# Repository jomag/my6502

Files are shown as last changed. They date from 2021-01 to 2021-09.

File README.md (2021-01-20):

# My 6502

I started watching [Ben Eaters](https://eater.net) [video series](https://eater.net/8bit)
where he builds a 6502 (actually, 65C02) based 8-bit computer from scratch
on breadboards. I thought it could be fun to follow along and build something similar,
but using real PCB's cause breadboards drive me crazy.

It might end up being something pretty to hang on the wall...

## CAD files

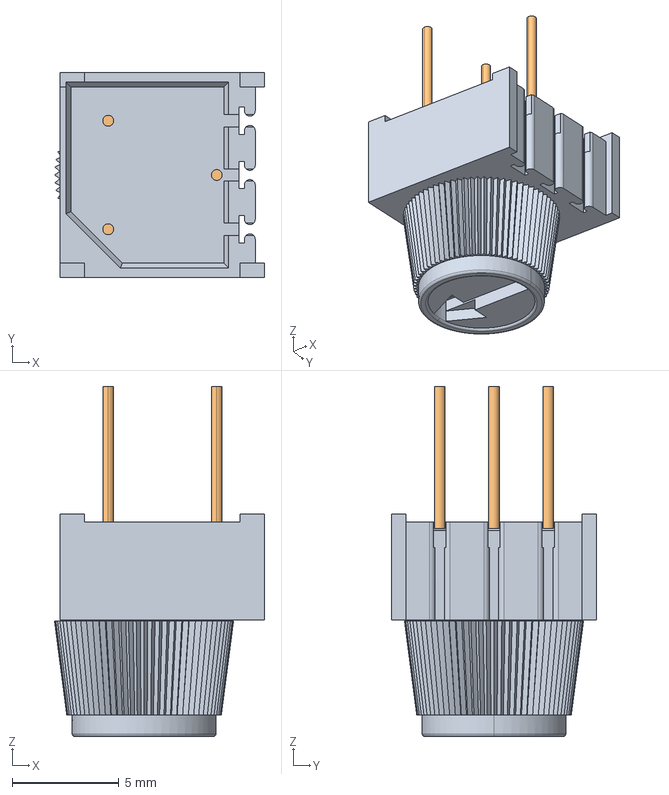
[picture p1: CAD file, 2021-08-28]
3d/3386F(T).stp
9.83 x 9.58 x 16.4 mm
MANIFOLD_SOLID_BREP_18751
MANIFOLD_SOLID_BREP_18840
MANIFOLD_SOLID_BREP_18929
MANIFOLD_SOLID_BREP_19018

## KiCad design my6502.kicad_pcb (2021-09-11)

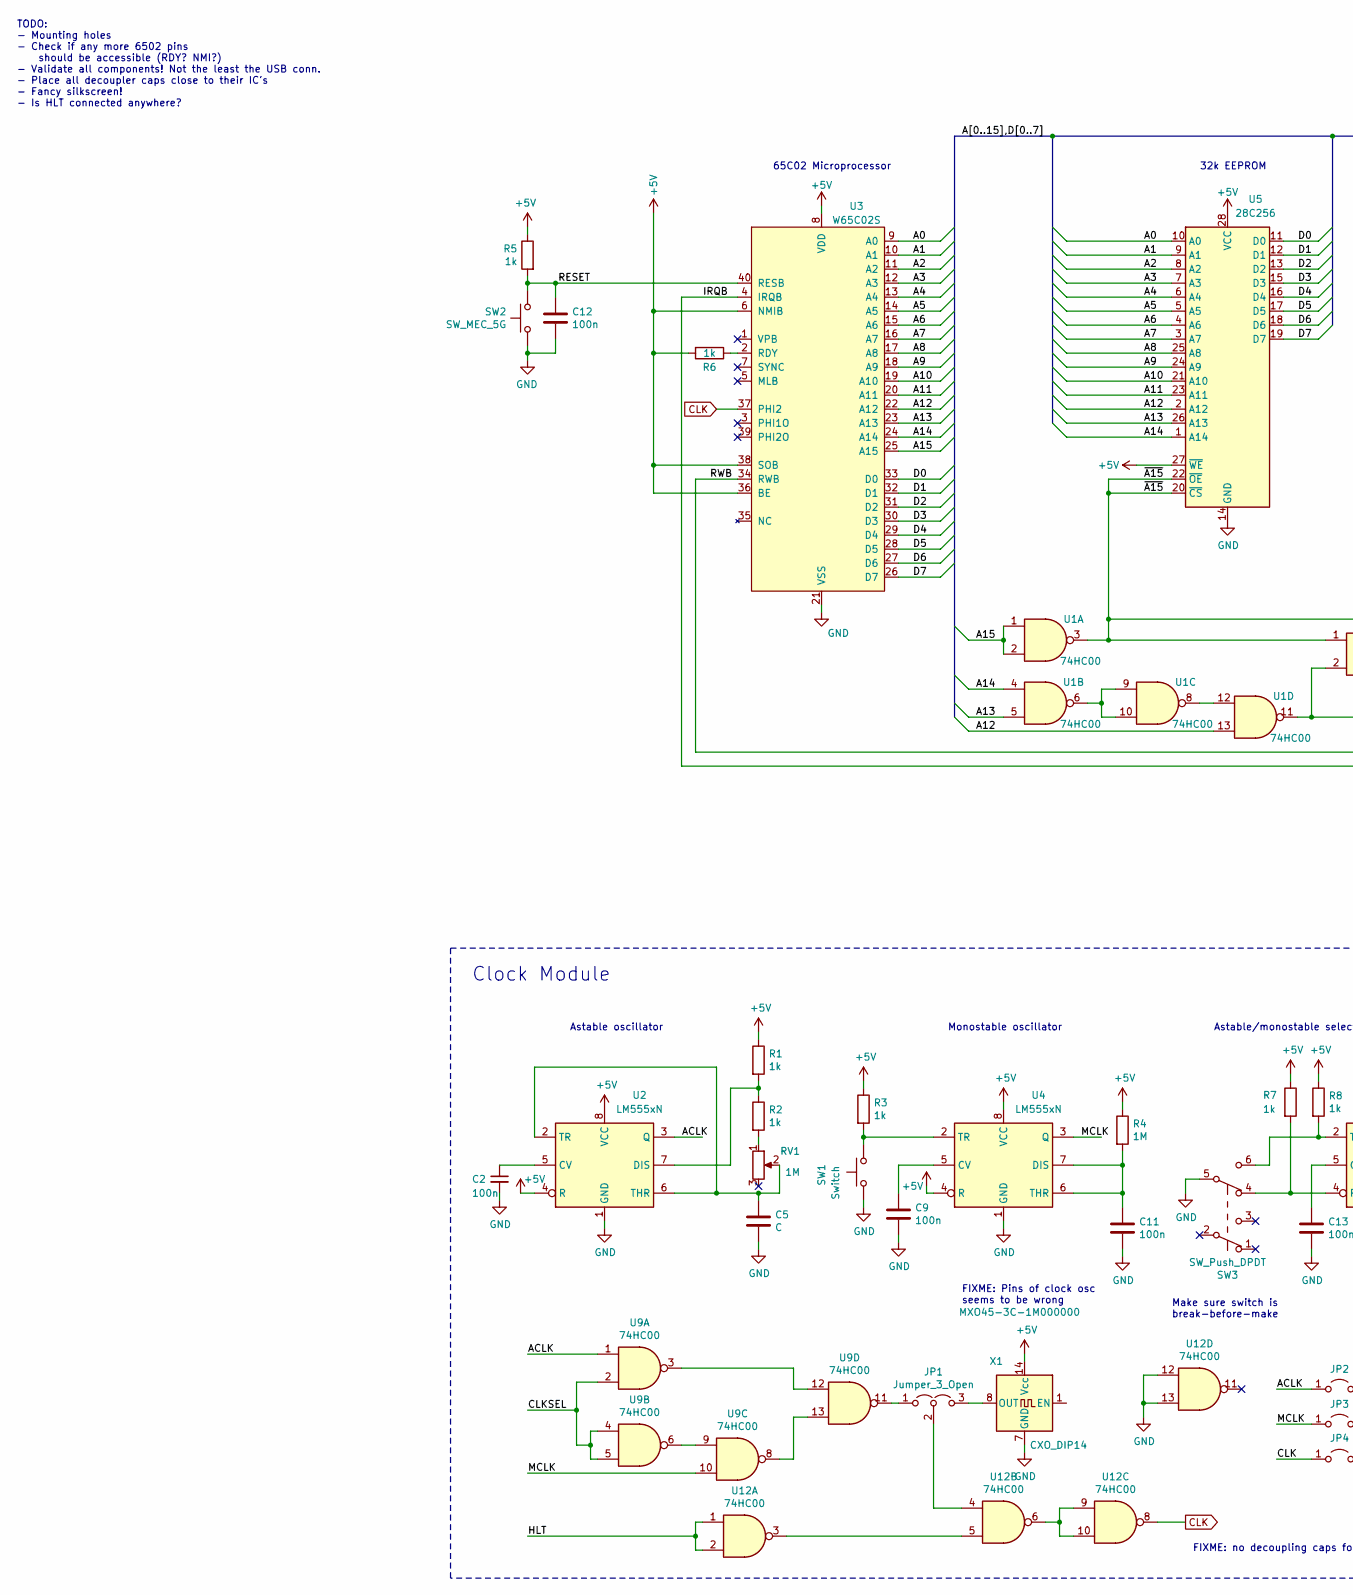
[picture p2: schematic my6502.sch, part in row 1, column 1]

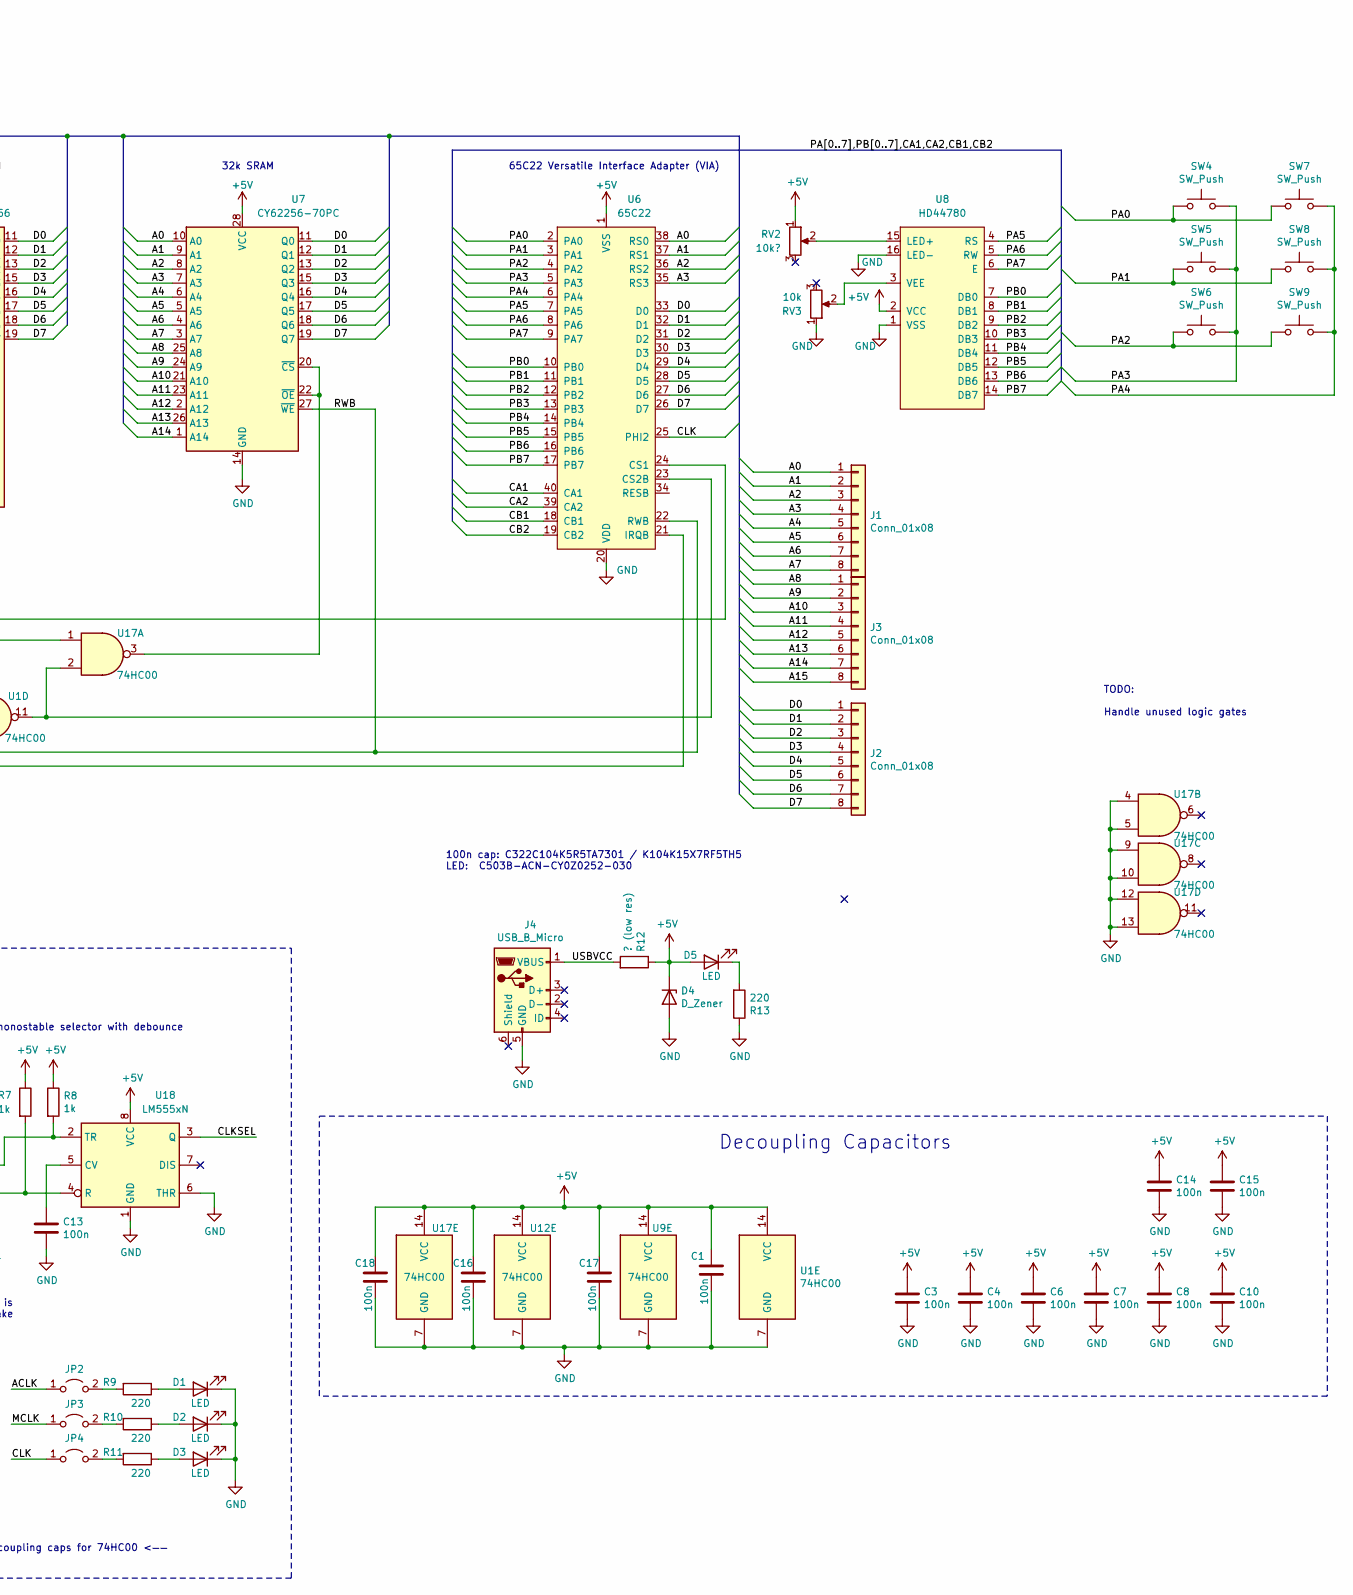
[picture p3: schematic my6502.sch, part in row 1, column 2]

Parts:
C1, C2, C3, C4, C6, C7, C8, C9, C10, C11, C12, C13, C14, C15, C16, C17, C18: 100n; C_Disc_D5.1mm_W3.2mm_P5.00mm
C5: C
D1, D2, D3, D5: LED; LED_D3.0mm
D4: D_Zener; D_A-405_P7.62mm_Horizontal
J1, J2, J3: Conn_01x08; PinHeader_1x08_P2.54mm_Vertical
J4: USB_B_Micro; USB_Micro-B_Molex_47346-0001
JP1: Jumper_3_Open; PinHeader_1x03_P2.54mm_Vertical
JP2, JP3, JP4: Jumper_2_Open; PinHeader_1x02_P2.54mm_Vertical
R1, R2, R3, R5, R6, R7, R8: 1k; R_Axial_DIN0207_L6.3mm_D2.5mm_P7.62mm_Horizontal
R4: 1M; R_Axial_DIN0207_L6.3mm_D2.5mm_P7.62mm_Horizontal
R9, R10, R11, R13: 220; R_Axial_DIN0207_L6.3mm_D2.5mm_P7.62mm_Horizontal
R12: ? (low res); R_Axial_DIN0207_L6.3mm_D2.5mm_P7.62mm_Horizontal
RV1: 1M; Potentiometer_Bourns_3386F_Vertical; Digi-Key 3386X-1-105TLF-ND
RV2: 10k?; Potentiometer_Bourns_3296W_Vertical
RV3: 10k; Potentiometer_Bourns_3296W_Vertical
SW1: Switch; SW_PUSH_6mm
SW2: SW_MEC_5G; SW_PUSH_6mm
SW3: SW_Push_DPDT
SW4: SW_Push; SW_PUSH_6mm; PartID Adafruit 4183
SW5, SW6, SW7, SW8, SW9: SW_Push; SW_PUSH_6mm
U1, U9, U12, U17: 74HC00; DIP-14_W7.62mm_LongPads
U2, U4, U18: LM555xN; DIP-8_W7.62mm
U3: W65C02S; DIP-40_W15.24mm_Socket_LongPads
U5: 28C256; DIP-28_W15.24mm_Socket_LongPads
U6: 65C22; DIP-40_W15.24mm_Socket_LongPads
U7: CY62256-70PC; DIP-28_W15.24mm
U8: HD44780; WC1602A
X1: CXO_DIP14; Oscillator_DIP-14; MPN MXO45-3C-1M000000

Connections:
+5V: C1.1, C3.1, C4.1, C6.1, C7.1, C8.1, C10.1, C14.1, C15.1, C16.1, C17.1, C18.1, D4.1 (K), D5.2 (A), R1.1, R3.1, R4.1, R5.1, R6.2, R7.1, R8.1, R12.1, RV2.1, U1.14 (VCC), U2.4 (R), U2.8 (VCC), U3.6 (NMIB), U3.8 (VDD), U3.36 (BE), U3.38 (SOB), U4.4 (R), U4.8 (VCC), U5.27 (~WE), U5.28 (VCC), U6.1 (VSS), U7.28 (VCC), U8.2 (VCC), U9.14 (VCC), U12.14 (VCC), U17.14 (VCC), U18.8 (VCC), X1.14 (Vcc)
/A0: J1.1, U3.9 (A0), U5.10 (A0), U6.38 (RS0), U7.10 (A0)
/A1: J1.2, U3.10 (A1), U5.9 (A1), U6.37 (RS1), U7.9 (A1)
/A2: J1.3, U3.11 (A2), U5.8 (A2), U6.36 (RS2), U7.8 (A2)
/A3: J1.4, U3.12 (A3), U5.7 (A3), U6.35 (RS3), U7.7 (A3)
/A4: J1.5, U3.13 (A4), U5.6 (A4), U7.6 (A4)
/A5: J1.6, U3.14 (A5), U5.5 (A5), U7.5 (A5)
/A6: J1.7, U3.15 (A6), U5.4 (A6), U7.4 (A6)
/A7: J1.8, U3.16 (A7), U5.3 (A7), U7.3 (A7)
/A8: J3.1, U3.17 (A8), U5.25 (A8), U7.25 (A8)
/A9: J3.2, U3.18 (A9), U5.24 (A9), U7.24 (A9)
/A10: J3.3, U3.19 (A10), U5.21 (A10), U7.21 (A10)
/A11: J3.4, U3.20 (A11), U5.23 (A11), U7.23 (A11)
/A12: J3.5, U1.13, U3.22 (A12), U5.2 (A12), U7.2 (A12)
/A13: J3.6, U1.5, U3.23 (A13), U5.26 (A13), U7.26 (A13)
/A14: J3.7, U1.4, U3.24 (A14), U5.1 (A14), U7.1 (A14)
/A15: J3.8, U1.1, U1.2, U3.25 (A15)
/ACLK: JP2.1 (A), U2.3 (Q), U9.1
/CLKSEL: U9.2, U9.4, U9.5, U18.3 (Q)
/D0: J2.1, U3.33 (D0), U5.11 (D0), U6.33 (D0), U7.11 (Q0)
/D1: J2.2, U3.32 (D1), U5.12 (D1), U6.32 (D1), U7.12 (Q1)
/D2: J2.3, U3.31 (D2), U5.13 (D2), U6.31 (D2), U7.13 (Q2)
/D3: J2.4, U3.30 (D3), U5.15 (D3), U6.30 (D3), U7.15 (Q3)
/D4: J2.5, U3.29 (D4), U5.16 (D4), U6.29 (D4), U7.16 (Q4)
/D5: J2.6, U3.28 (D5), U5.17 (D5), U6.28 (D5), U7.17 (Q5)
/D6: J2.7, U3.27 (D6), U5.18 (D6), U6.27 (D6), U7.18 (Q6)
/D7: J2.8, U3.26 (D7), U5.19 (D7), U6.26 (D7), U7.19 (Q7)
/HLT: U12.1, U12.2
/IRQB: U3.4 (IRQB), U6.21 (IRQB)
/MCLK: JP3.1 (A), U4.3 (Q), U9.10
/PA0: SW4.1, SW7.1, U6.2 (PA0)
/PA1: SW5.1, SW8.1, U6.3 (PA1)
/PA2: SW6.1, SW9.1, U6.4 (PA2)
/PA3: SW4.2, SW5.2, SW6.2, U6.5 (PA3)
/PA4: SW7.2, SW8.2, SW9.2, U6.6 (PA4)
/PA5: U6.7 (PA5), U8.4 (RS)
/PA6: U6.8 (PA6), U8.5 (RW)
/PA7: U6.9 (PA7), U8.6 (E)
/PB0: U6.10 (PB0), U8.7 (DB0)
/PB1: U6.11 (PB1), U8.8 (DB1)
/PB2: U6.12 (PB2), U8.9 (DB2)
/PB3: U6.13 (PB3), U8.10 (DB3)
/PB4: U6.14 (PB4), U8.11 (DB4)
/PB5: U6.15 (PB5), U8.12 (DB5)
/PB6: U6.16 (PB6), U8.13 (DB6)
/PB7: U6.17 (PB7), U8.14 (DB7)
/RESET: C12.1, R5.2, SW2.1, U3.40 (RESB)
/RWB: U3.34 (RWB), U6.22 (RWB), U7.27 (~WE)
/USBVCC: J4.1 (VBUS), R12.2
/~A15: U1.3, U5.20 (~CS), U5.22 (~OE), U6.24 (CS1), U17.1
CLK: JP4.1 (A), U3.37 (PHI2), U6.25 (PHI2), U12.8
GND: C1.2, C2.2, C3.2, C4.2, C5.2, C6.2, C7.2, C8.2, C9.2, C10.2, C11.2, C12.2, C13.2, C14.2, C15.2, C16.2, C17.2, C18.2, D1.1 (K), D2.1 (K), D3.1 (K), D4.2 (A), J4.5 (GND), R13.1, RV3.1, SW1.1, SW2.2, SW3.5 (B), U1.7 (GND), U2.1 (GND), U3.21 (VSS), U4.1 (GND), U5.14 (GND), U6.20 (VDD), U7.14 (GND), U8.1 (VSS), U8.16 (LED-), U9.7 (GND), U12.7 (GND), U12.12, U12.13, U17.4, U17.5, U17.7 (GND), U17.9, U17.10, U17.12, U17.13, U18.1 (GND), U18.6 (THR), X1.7 (GND)
unnamed: C2.1, U2.5 (CV)
unnamed: C5.1, RV1.2, U2.2 (TR), U2.6 (THR)
unnamed: C9.1, U4.5 (CV)
unnamed: C11.1, R4.2, U4.6 (THR), U4.7 (DIS)
unnamed: C13.1, U18.5 (CV)
unnamed: D1.2 (A), R9.1
unnamed: D2.2 (A), R10.1
unnamed: D3.2 (A), R11.1
unnamed: D5.1 (K), R13.2
unnamed: JP1.1 (A), U9.11
unnamed: JP1.2 (C), U12.4
unnamed: JP1.3 (B), X1.8 (OUT)
unnamed: JP2.2 (B), R9.2
unnamed: JP3.2 (B), R10.2
unnamed: JP4.2 (B), R11.2
unnamed: R1.2, R2.1, U2.7 (DIS)
unnamed: R2.2, RV1.1
unnamed: R3.2, SW1.2, U4.2 (TR)
unnamed: R6.1, U3.2 (RDY)
unnamed: R7.2, SW3.4 (A), U18.4 (R)
unnamed: R8.2, SW3.6 (C), U18.2 (TR)
unnamed: RV2.2, U8.15 (LED+)
unnamed: RV3.2, U8.3 (VEE)
unnamed: U1.6, U1.9, U1.10
unnamed: U1.11, U6.23 (CS2B), U17.2
unnamed: U1.8, U1.12
unnamed: U9.6, U9.9
unnamed: U9.3, U9.12
unnamed: U9.8, U9.13
unnamed: U12.3, U12.5
unnamed: U12.6, U12.9, U12.10
unnamed: U7.20 (~CS), U7.22 (~OE), U17.3

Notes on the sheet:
Clock Module
Astable oscillator
Decoupling Capacitors
32k EEPROM
65C02 Microprocessor
65C22 Versatile Interface Adapter (VIA)
32k SRAM
TODO: Handle unused logic gates
Make sure switch is break-before-make
Astable/monostable selector with debounce
Monostable oscillator
FIXME: Pins of clock osc seems to be wrong
FIXME: no decoupling caps for 74HC00 <——
100n cap: C322C104K5R5TA7301 / K104K15X7RF5TH5 LED: C503B-ACN-CY0Z0252-030
TODO: - Mounting holes - Check if any more 6502 pins should be accessible (RDY? NMI?) - Validate all components! Not the least the USB conn. - Place all decoupler caps close to their IC's - Fancy silkscreen! - Is HLT connected anywhere?

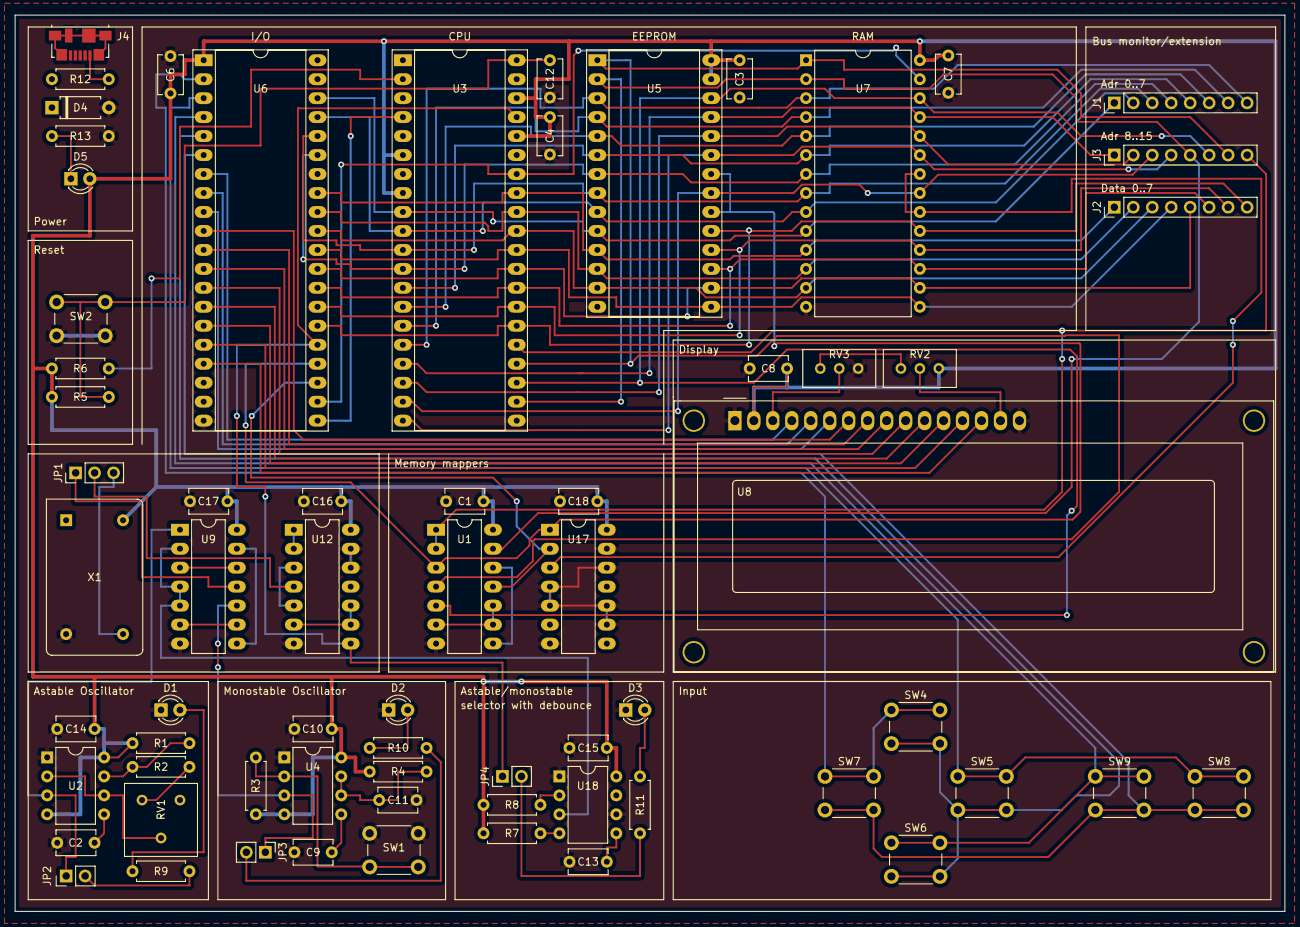
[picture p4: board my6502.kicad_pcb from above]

Board: 4 copper layers, 170.0 x 120.0 mm, 67 parts (0 on the bottom side), 84 nets.

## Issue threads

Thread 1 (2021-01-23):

Add solder pad/through hole for every pin on 6502 and 6522

jomag, 2021-01-23:
It would be nice to be able easily access every pin either through a header or by soldering something to a solder pad. Should be placed right next to the sockets.

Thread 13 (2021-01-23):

Power from battery?

jomag, 2021-01-23:
Would it be possible to power the computer from battery?

jomag, 2021-01-23:
An obvious alternative is to use USB and a power bank.

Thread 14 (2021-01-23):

Automatic suspend

jomag, 2021-01-23:
Especially if battery is used, it would be nice if we could turn on the device with a push button and have it automatically turn off after some time. Or, as an alternative, have the computer turn itself off after some time, but that would require some code to get right. Maybe a help MCU, an 8-pin AVR for example, could be used.

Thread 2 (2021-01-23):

Add solder jumpers for all data lines?

jomag, 2021-01-23:
If solder jumpers are used for more or less all pins then it would be easy to desolder or cut these jumpers to change the functionality of the board.

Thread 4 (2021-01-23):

Add LED's for address, data and VIA

jomag, 2021-01-23:
It would be nice to monitor exactly what's happening all the time by having LED's for every data and address line (at least). This would probably need a buffer of some kind.

jomag, 2021-01-24:
Probably a good idea to add a driver between the bus and LED's. 74HC245 could work.

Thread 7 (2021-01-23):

Easily flashable EEPROM alternative

jomag, 2021-01-23:
It would be nice to have an alternative to using an off-board EEPROM programmer when reprogramming the chip. Investigate if there are any suitable chips available. Another alternative would be to create a small Arduino clone with the same footprint as the EEPROM chip and let it act as memory.

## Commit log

2021-01-21 Added VIA 65C22
    [my6502.sch]
2021-01-21 Add RAM
    [my6502.sch]
2021-01-22 Add minimal 555-based clock module
    [my6502.sch]
2021-01-23 Add manual clock pulse button (incomplete)
    [my6502.sch]
2021-01-23 Incomplete work on primarily display and keys
    [my6502.sch]
2021-02-13 Uncomitted changes
    [my6502.sch]
2021-04-18 Updates to the clock module
    [my6502.sch]
2021-04-22 Pick footprints for a many components
    [my6502.kicad_pcb, my6502.sch]
2021-05-16 placed most components
    [my6502.kicad_pcb, my6502.sch]
2021-05-25 USB connector, overvoltage protection, ...
    [my6502.kicad_pcb, my6502.sch]
2021-08-24 Mostly minor adjustments
    [my6502.kicad_pcb, my6502.sch]
2021-08-28 Some components decided on and initial routing
    [3386F(T).stp, my6502.kicad_pcb, my6502.sch]
2021-08-29 More routing
    [my6502.kicad_pcb]
2021-09-06 many routes
    [my6502.kicad_pcb, my6502.sch]
2021-09-11 only 3 routes remaining
    [my6502.kicad_pcb]
